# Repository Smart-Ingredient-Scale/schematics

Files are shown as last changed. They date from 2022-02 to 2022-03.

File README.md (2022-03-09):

# **ECE 477: Smart Kitchen Scale Schematics**

EAGLE PCB Design Tool

**Last Updated**: Mar 9, 2022

<h2 style="color: salmon" > <b> Repository Structure </b> </h2>

```
├── datasheets      # Directory for datasheets
├── docs            # file for library config
├── img             # Images folder for documentation
├── pcb             # Directory of schematics and board design files
└── README.md       

```

<h2 style="color: salmon" > <b> Schematic Design Responsibilities </b> </h2>

- [x] Design `Load Cell` subcircuit
- [x] Design `SPI Touchscreen` headers + &mu;C connections
- [x] Design `Battery Recharging` subcircuit
- [x] Design `Seven Segment Display` wire SPI pins + VDD/GND
- [x] Design `MCU Debugger` subcircuit
- [x] Integrate all submodules (MCU, battery, plugs, buttons, etc.)
- [x] Be a potato

<h2 style="color: salmon" > <b> Board Design Responsibilities </b> </h2>

- [x] Design PCB Revision 1.0.
- [ ] Verify PCB Revision 1.0 with course staff
- [ ] Order PCB via `JLCPCB` service
- [ ] Order a mask for component soldering via `JLCPCB` service

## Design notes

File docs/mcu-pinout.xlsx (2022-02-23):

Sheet: Pin Claiming
LQFP64 Pins | STM32F401RE Pin Number | Alternate Function | PCB Label |  | LQFP64 Pins | STM32F401RE Pin Number | Alternate Function | PCB Label
PA0 | 14 | ADC1_IN0 |  |  | PC0 | 8 | ADC1_IN10 | PC0
PA1 | 15 | ADC1_IN1 |  |  | PC1 | 9 | ADC_IN11 | PC1
PA2 | 16 | ADC1_IN2 |  |  | PC2 | 10 | ADC_IN12 | PC2
PA3 | 17 | ADC1_IN3 |  |  | PC3 | 11 | ADC_IN13 | PC3
PA4 | 20 | SPI1_NSS | SS_CS |  | PC4 | 24 | ADC1_IN14 | X-
PA5 | 21 | SPI1_SCK | SS_SCK |  | PC5 | 25 | ADC1_IN15 | Y-
PA6 | 22 | SPI1_MISO | SS_MISO |  | PC6 | 37 | --- | TFT_DC
PA7 | 23 | SPI1_MOSI | SS_MOSI |  | PC7 | 38 | --- | TFT_RST
PA8 | 41 | --- | SD_DC |  | PC8 | 39 | TIM3_CH3 | LITE
PA9 | 42 | --- | SD_DET |  | PC9 | 40 | --- | SD_CS
PA10 | 43 | TIM1_CH3 | PA10 |  | PC10 | 51 | SPI3_SCK | OLED_SCK
PA11 | 44 | TIM1_CH4 | PA11 |  | PC11 | 52 | --- | OLED_NSS
PA12 | 45 | TIM1_ETR | PA12 |  | PC12 | 53 | SPI3_MOSI | OLED_MOSI
PA13 | 46 | SWDIO | SWDIO |  | PC13 | 2
PA14 | 49 | SWCLK | SWCLK |  | PC14 | OSC32_IN | 32kHz Ext Osc |  | see next page
PA15 | 50 | JTDI |  |  | PC15 | OSC32_OUT | 32kHz Ext Osc |  | see next page
PB0 | 26 | ADC1_IN8 | Y+ |  | PD2 | 54 | ---
PB1 | 27 | ADC1_IN9 | X+
PB2 | 28 | --- |  |  | VBAT | 1 | --- | VDD
PB3 | 55 | SPIx_CLK | PB3 |  | PH0-OSC_IN | 5 | HSE Crystal | ???
PB4 | 56 | SPIx_MISO | PB4 |  | PH1-OSC_OUT | 6 | HSE Crystal | ???
PB5 | 57 | SPIx_MOSI | PB5 | del | nRST | 7 | --- | NRST
PB6 | 58 | I2C1_SCL | MEM_SCL |  | VSSA | 12 | VREF- Analog | GND
PB7 | 59 | I2C1_SDA | MEM_SDA |  | VDDA | 13 | VREF+ Analog | VDDA
PB8 | 61 | --- | HX_DATA |  | VSS | 18, 31, 47, 63 | GND | GND
PB9 | 62 | TIM4_CH4 | HX_CLK |  | VDD | 19, 32, 48, 64 | 3.3V | 3V3
PB10 | 29 |  |  |  | VCAP1 | 22 | PWR→VOS | 10uF || 100nF
PB11 | N/A |  |  |  | BOOT0 | 60 | ??? | GND
PB12 | 33 | --- | TFT_CS
PB13 | 34 | SPI2_CLK | TFT_SCK |  | KEY
PB14 | 35 | SPI2_MISO | TFT_MISO |  | Inflexible |  | See next page/sheet about hardware info
PB15 | 36 | SPI2_MOSI | TFT_MOSI |  | Preferable
 |  |  |  |  | Flexible | ← verify
 |  | Bold = using |  |  | Extra (Redundant) | ← low priority | Bold = using
 |  | normal = capable |  |  | Unused |  | normal = capable
 |  | --- = GPIO |  |  |  |  | --- = GPIO
 |  | (1) How do we specify our 3.3V LDO regulator, not internal? You don’t. You just provide 3.3V to VDD with the LDO. (2) How do we set our VDDA pin? Is it internally regulated? Same 3.3V source as VDD (or separate regulator). (3) How do we bias BOOT0? Tie to GND for SWD interface. (4) Are the PH0 and PH1 pins for the HSE crystal? Yes, they are. See the typical application circuit to the right. (5) Do we use VCAP1? If using internal regulator, 4.7uF low ESR, else 100nF. (6) What does VBAT do? What is the best biasing? Used only when VDD not present for RTC and backup. Tie to VDD.

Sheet: Power Supply Info
LQFP64 Pins | STM32F401RE Pin Number | Alternate Function | PCB Label | Design Notes
VBAT | 1 | --- | VDD
PH0-OSC_IN | 5 | HSE Crystal | HSE_IN | Use 16 Mhz oscillator
PH1-OSC_OUT | 6 | HSE Crystal | HSE_OUT | Use 16 Mhz oscillator
nRST | 7 | --- | NRST | Debounce using RC circuit
VSSA | 12 | VREF- Analog | GND | Attach to GND plane
VDDA | 13 | VREF+ Analog | VDDA | Same level as VDD
VSS | 18, 31, 47, 63 | GND | GND | Attach to GND plane
VDD | 19, 32, 48, 64 | 3.3V | 3V3 | Output of 3.3V external regulator
VCAP1 | 22 | --- | 10uF || 100nF | 1.2V (handle internally)
BOOT0 | 60 | --- | GND | Tie to GND if using SWD interface
KEY
Inflexible
Desirable
Flexible
Unused
 |  |  |  |  | (1) How do we specify our 3.3V LDO regulator, not internal? You don’t. You just provide 3.3V to VDD with the LDO. (2) How do we set our VDDA pin? Is it internally regulated? Same 3.3V source as VDD (or separate regulator). (3) How do we bias BOOT0? Tie to GND for SWD interface. (4) Are the PH0 and PH1 pins for the HSE crystal? Yes, they are. See the typical application circuit to the right. (5) Do we use VCAP1? If using internal regulator, 4.7uF low ESR, else 100nF. (6) What does VBAT do? What is the best biasing? Used only when VDD not present for RTC and backup. Tie to VDD.

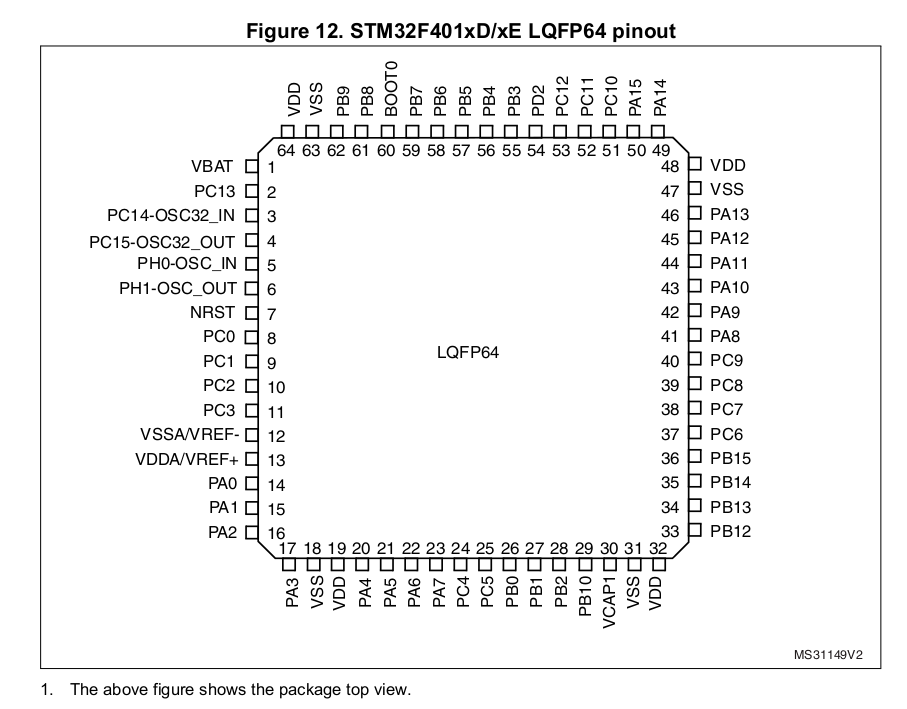
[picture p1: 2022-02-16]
img/stm32f401re-pinout.png

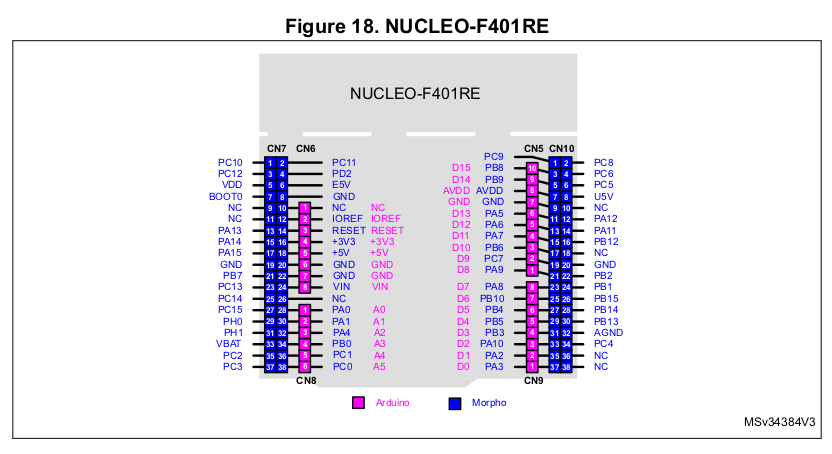
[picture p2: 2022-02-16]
img/nucleo-f401re-pinout.png

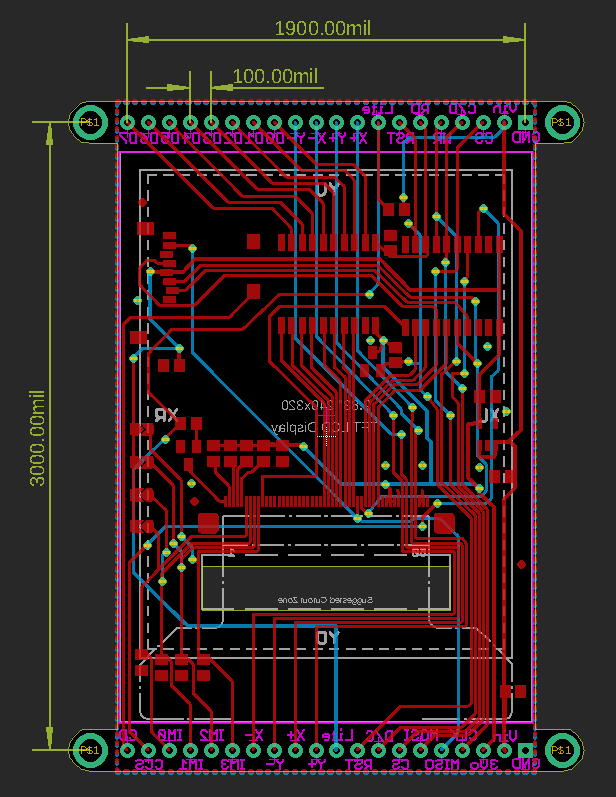
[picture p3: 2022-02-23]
img/lcd-tft-dimensions.png

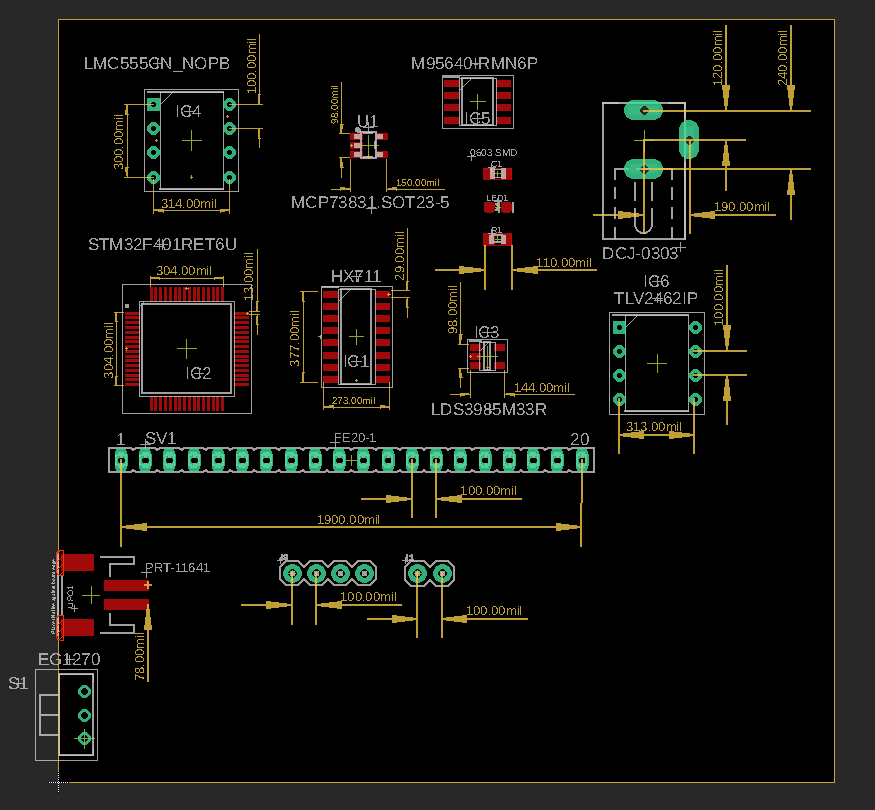
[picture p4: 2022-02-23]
img/pcb-footprints.png

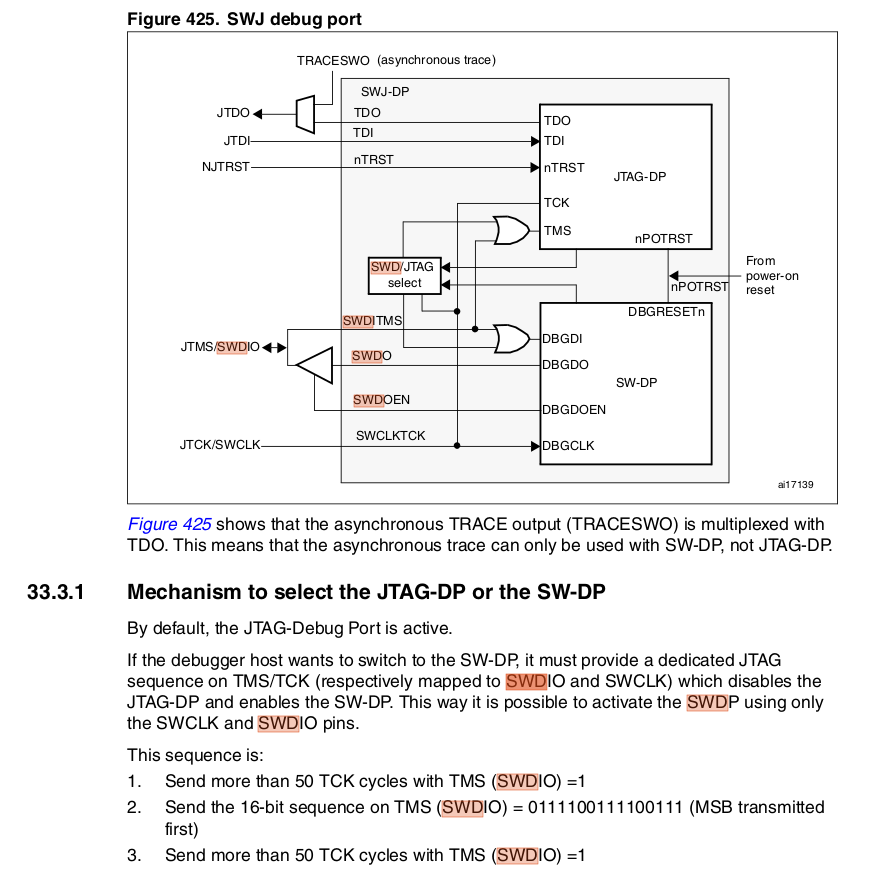
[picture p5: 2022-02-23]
img/swd-interface.png

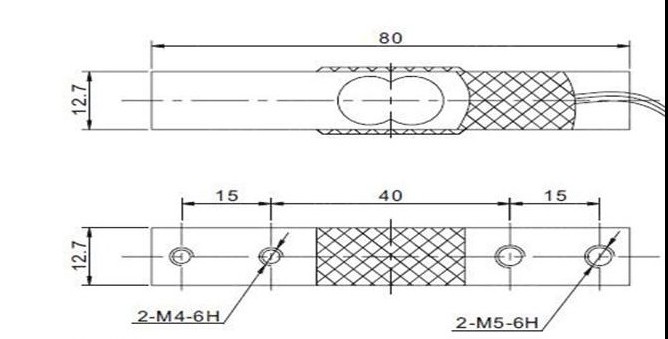
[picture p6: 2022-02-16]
img/load-cell-4540-dimensions.jpg

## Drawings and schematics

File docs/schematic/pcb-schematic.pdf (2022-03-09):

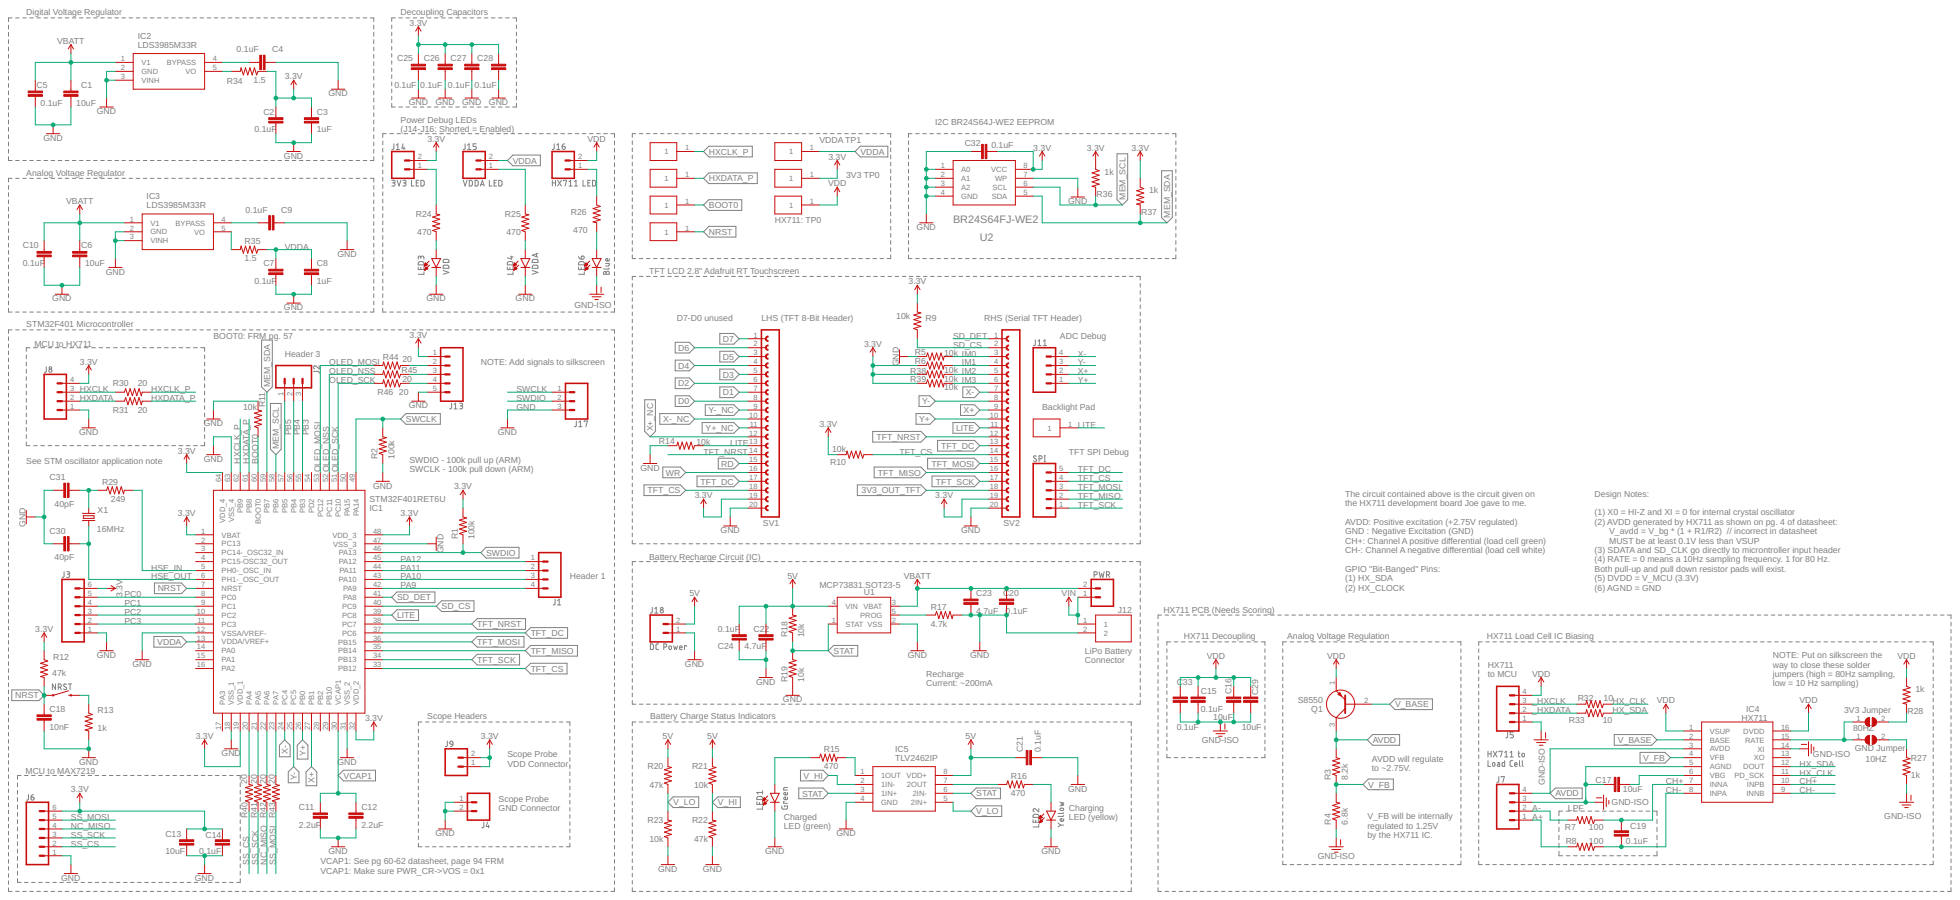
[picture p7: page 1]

Decoupling Capacitors
3.3V GND GND GND GND

TFT LCD 2.8" Adafruit RT Touchscreen

ADC Debug Backlight Pad TFT SPI Debug

NOTE: Add signals to silkscreen

See STM oscillator application note

SWDIO - 100k pull up (ARM) SWCLK - 100k pull down (ARM)

The circuit contained above is the circuit given on
the HX711 development board Joe gave to me. AVDD: Positive excitation (+2.75V regulated) GND : Negative Excitation (GND) CH+: Channel A positive differential (load cell green) CH-: Channel A negative differential (load cell white) GPIO "Bit-Banged" Pins: (1) HX_SDA

Design Notes: (1) X0 = HI-Z and XI = 0 for internal crystal oscillator

(2) AVDD generated by HX711 as shown on pg. 4 of datasheet: V_avdd = V_bg * (1 + R1/R2) // incorrect in datasheet MUST be at least 0.1V less than VSUP

(3) SDATA and SD_CLK go directly to microntroller input header
(4) RATE = 0 means a 10Hz sampling frequency. 1 for 80 Hz. Both pull-up and pull down resistor pads will exist. (5) DVDD = V_MCU (3.3V)

Battery Recharge Circuit (IC)

Battery Charge Status Indicators

Scope Probe GND Connector

LPF VCAP1: See pg 60-62 datasheet, page 94 FRM
2.2uF GND

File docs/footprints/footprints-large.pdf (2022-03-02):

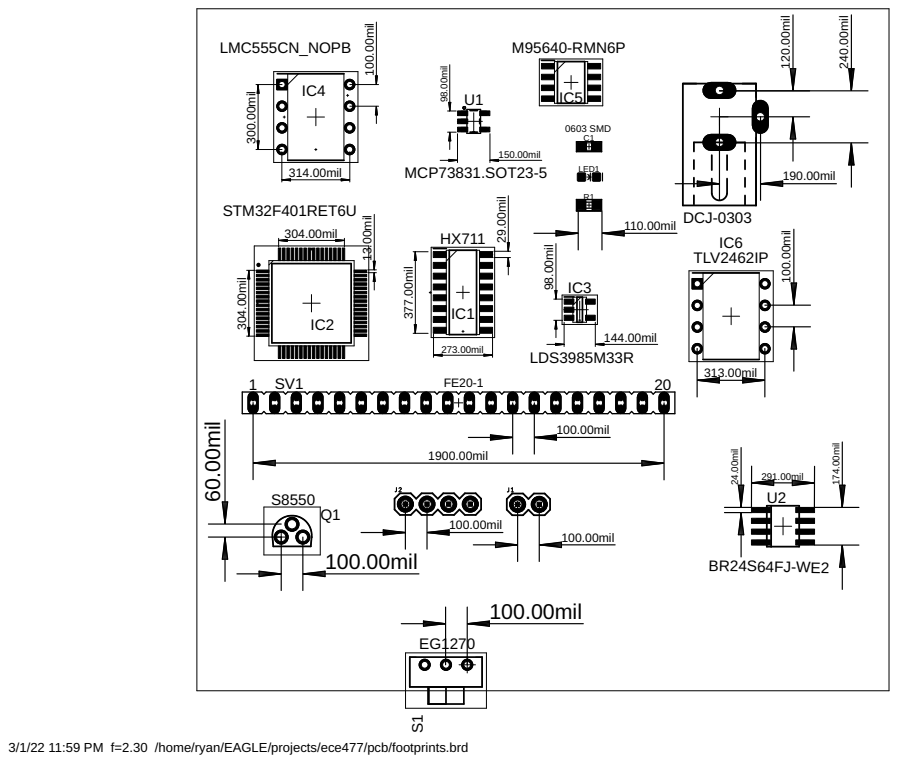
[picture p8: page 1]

3/1/22 11:59 PM f=2.30 /home/ryan/EAGLE/projects/ece477/pcb/footprints.brd

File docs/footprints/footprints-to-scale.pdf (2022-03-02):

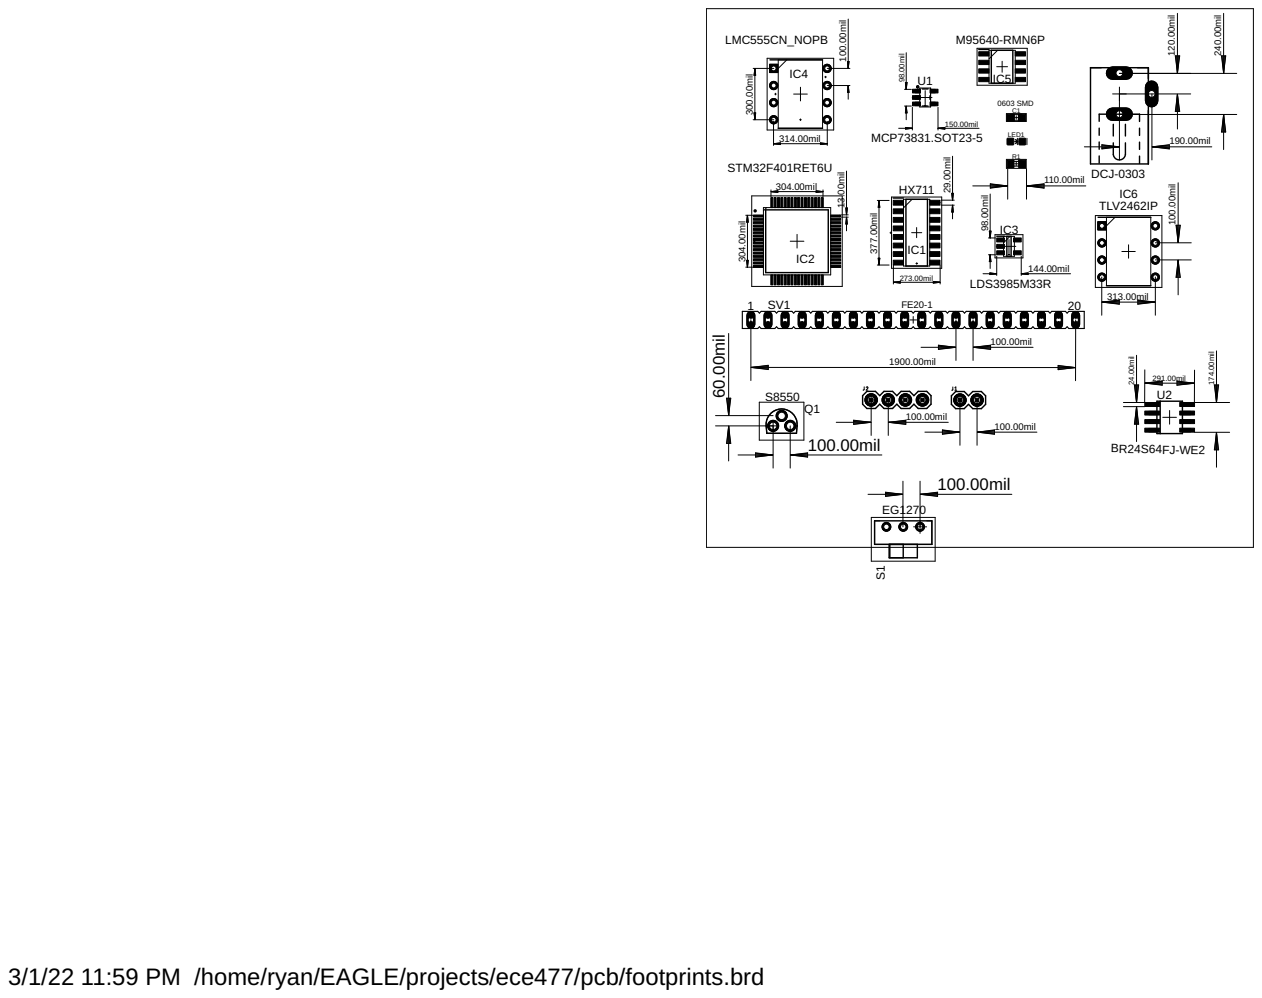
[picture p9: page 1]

3/1/22 11:59 PM /home/ryan/EAGLE/projects/ece477/pcb/footprints.brd

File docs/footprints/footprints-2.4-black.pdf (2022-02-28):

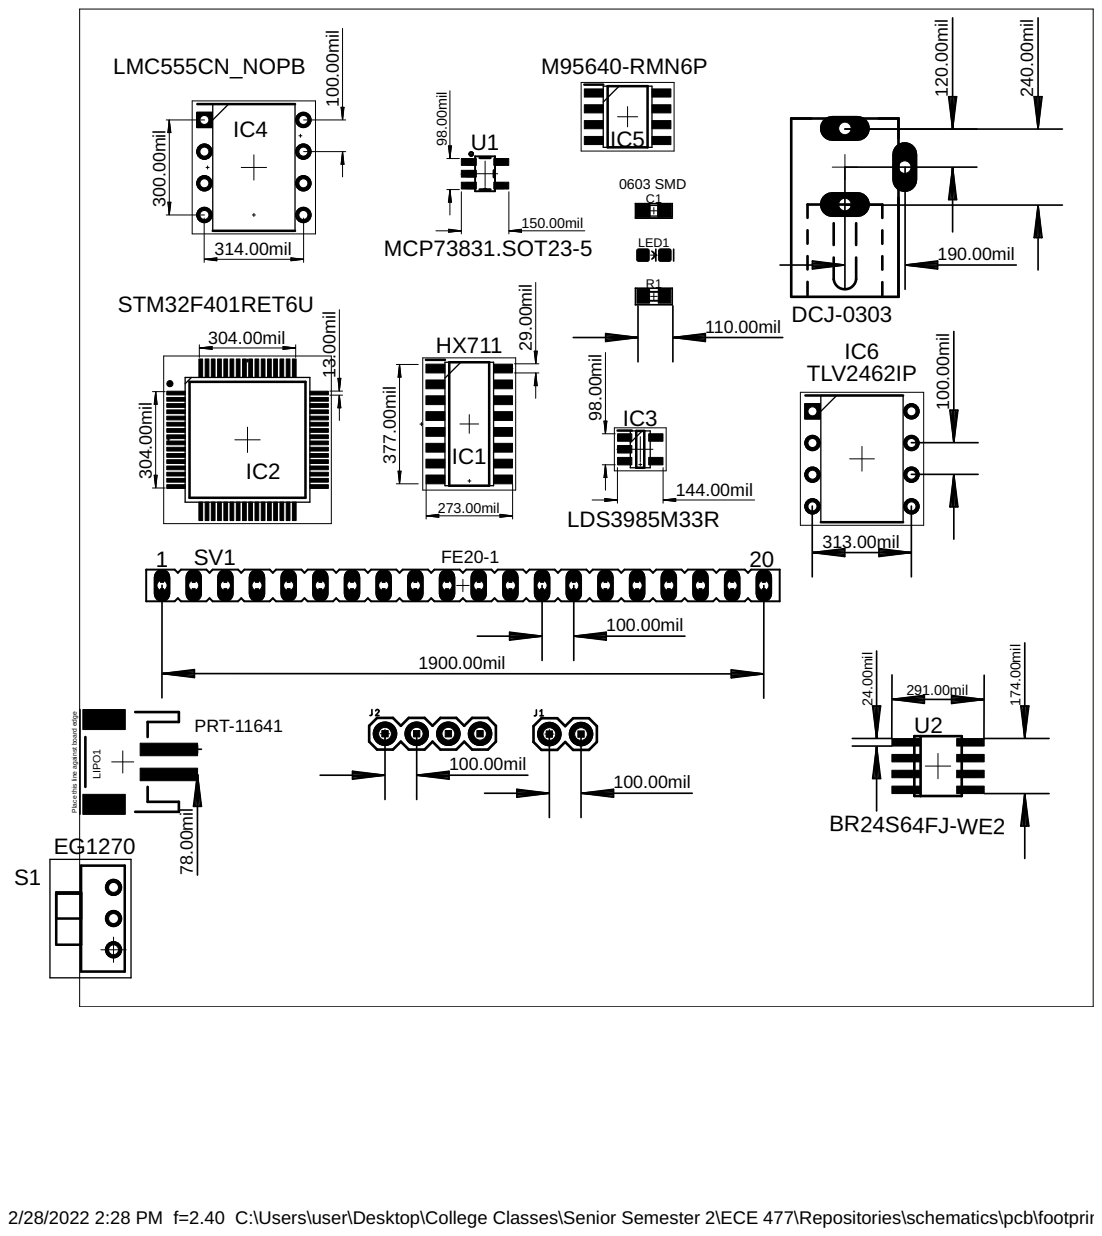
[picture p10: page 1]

Place this line against board edge

2/28/2022 2:28 PM f=2.40 C:\Users\user\Desktop\College Classes\Senior Semester 2\ECE 477\Repositories\schematics\pcb\footprints.brd

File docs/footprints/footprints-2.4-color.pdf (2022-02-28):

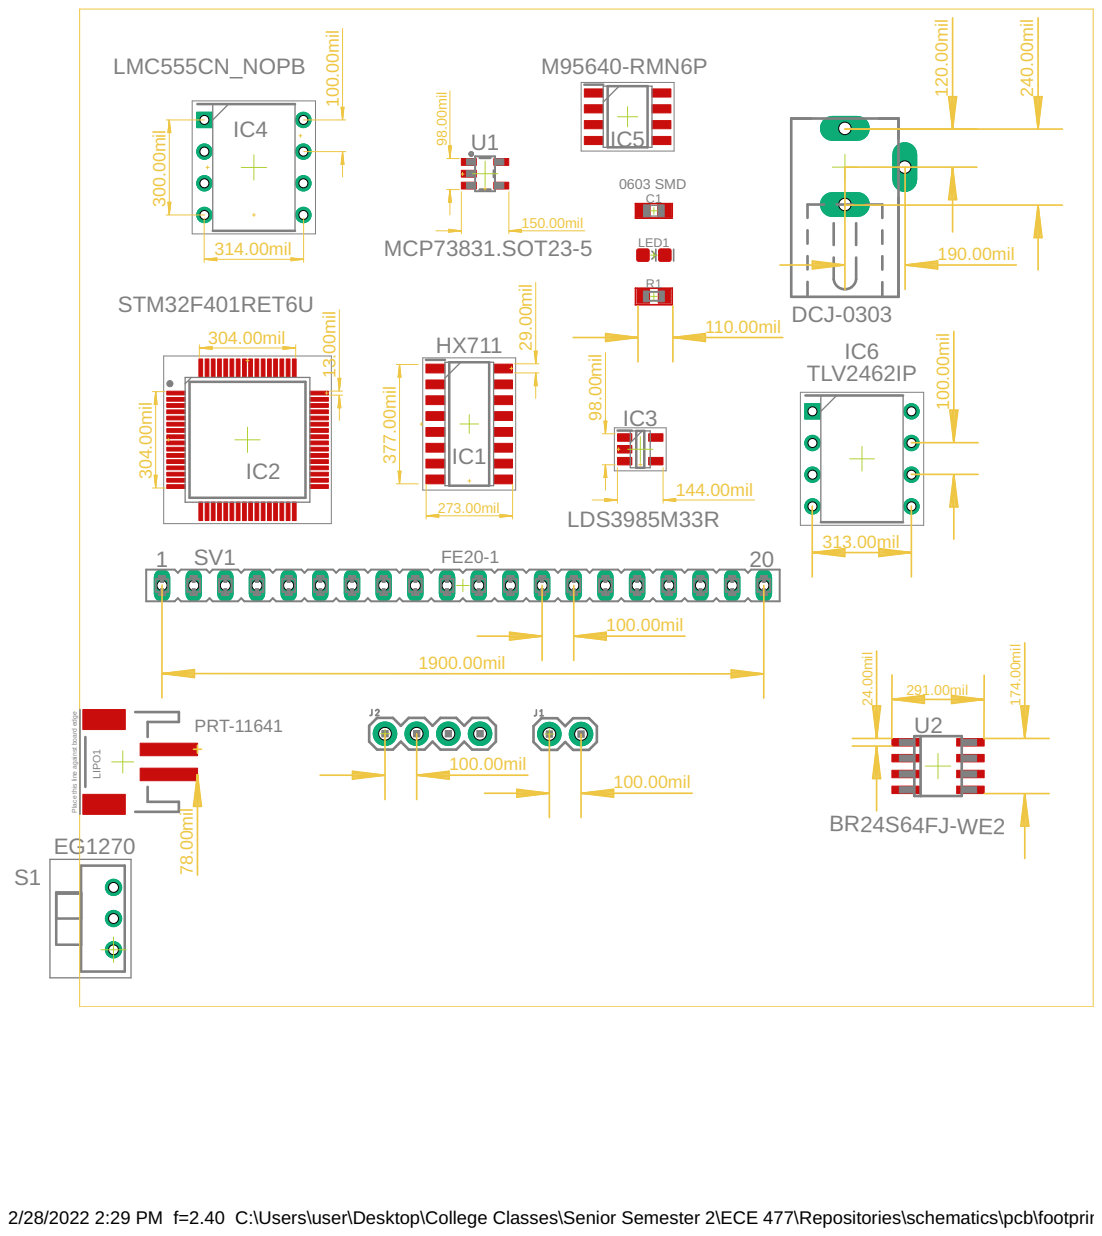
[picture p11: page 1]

Place this line against board edge

2/28/2022 2:29 PM f=2.40 C:\Users\user\Desktop\College Classes\Senior Semester 2\ECE 477\Repositories\schematics\pcb\footprints.brd

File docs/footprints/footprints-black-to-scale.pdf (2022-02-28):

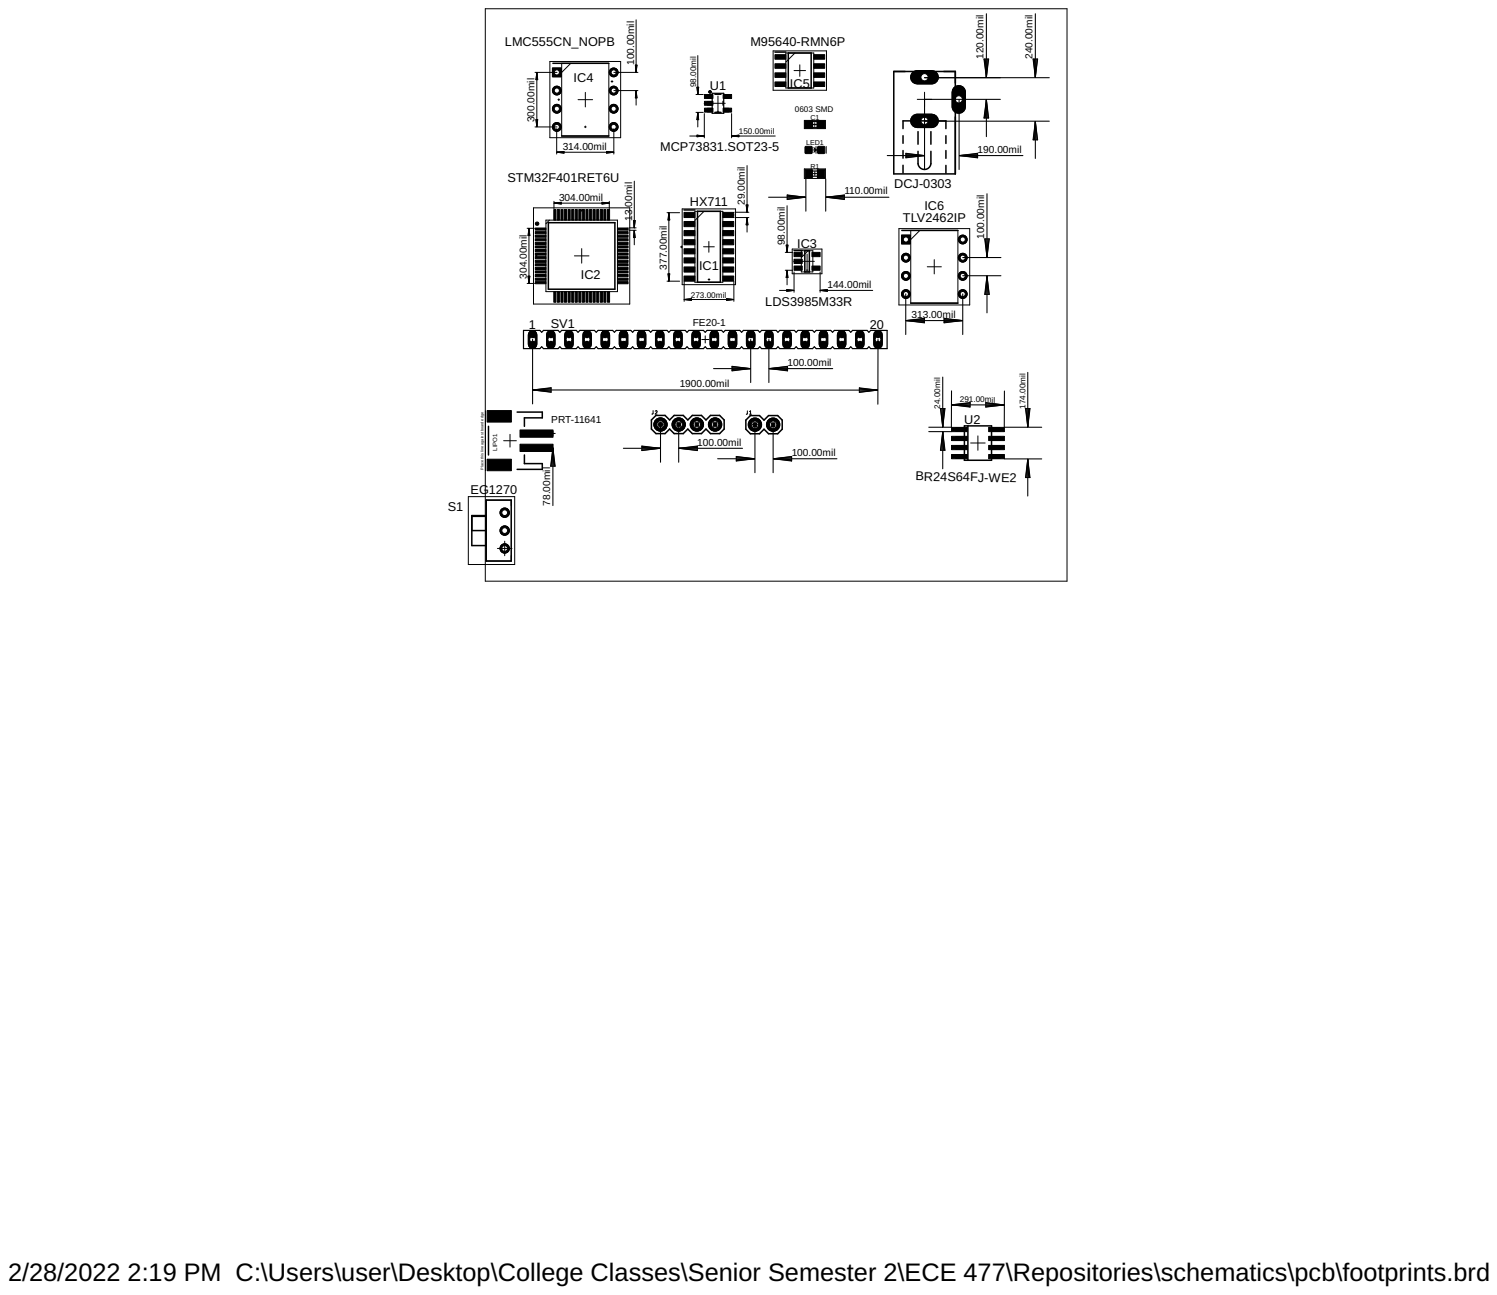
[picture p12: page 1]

Place this line against board edge

2/28/2022 2:19 PM C:\Users\user\Desktop\College Classes\Senior Semester 2\ECE 477\Repositories\schematics\pcb\footprints.brd

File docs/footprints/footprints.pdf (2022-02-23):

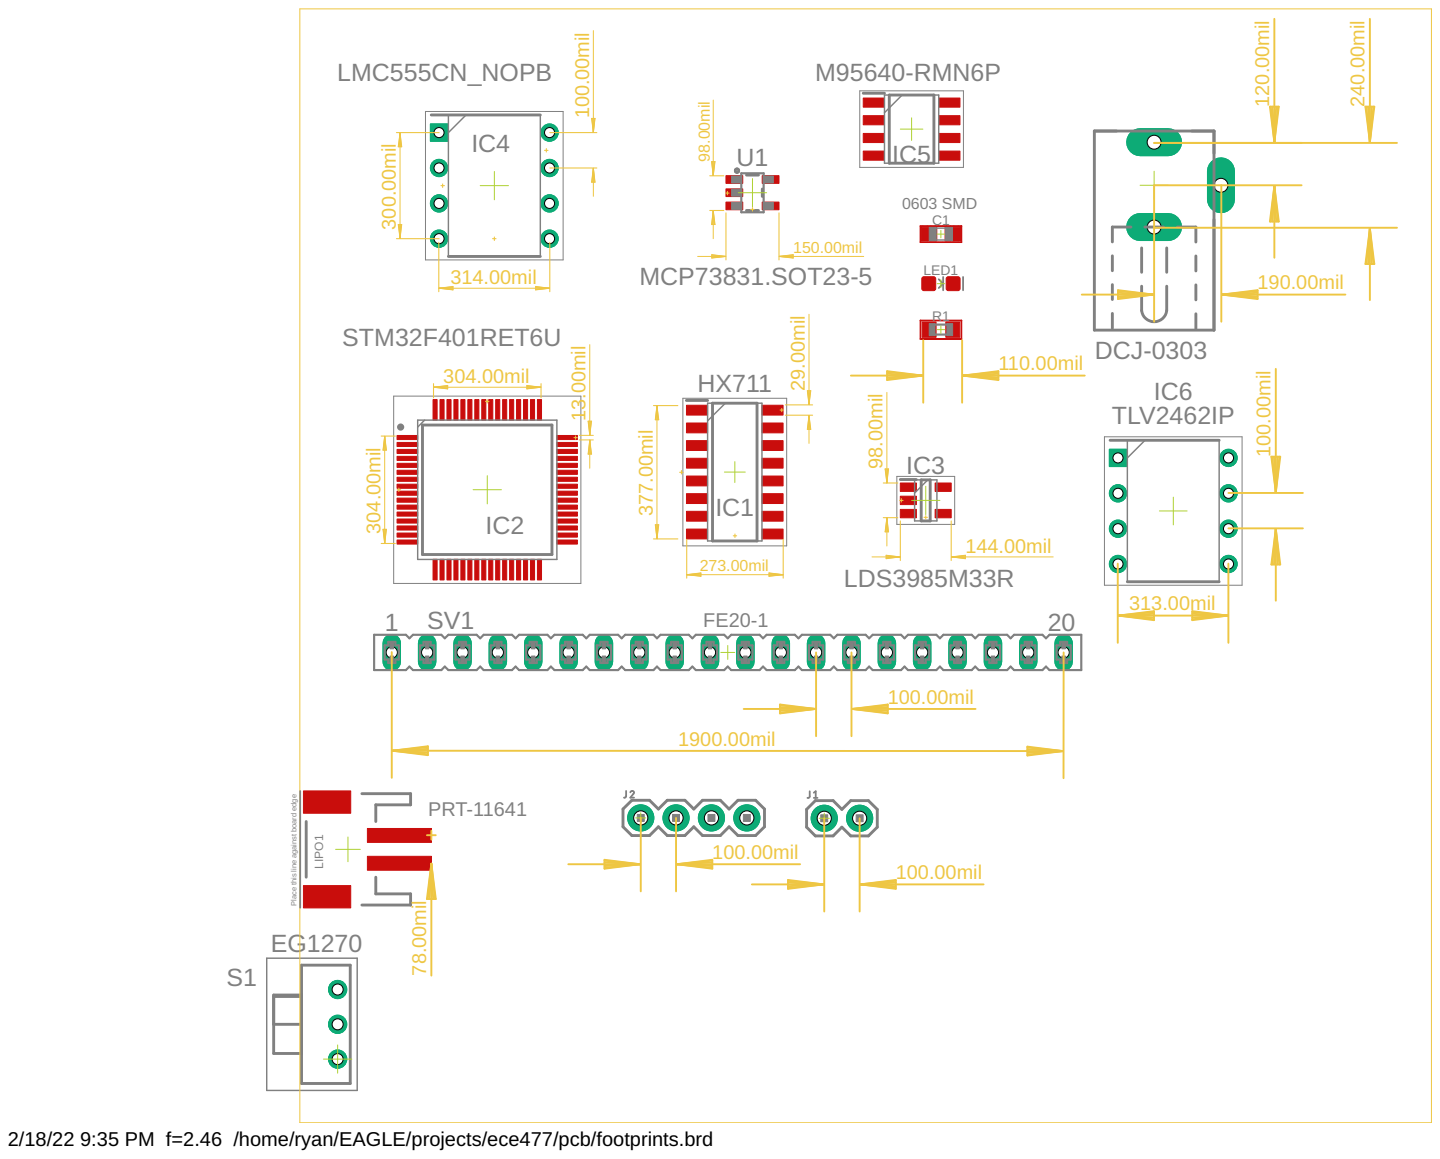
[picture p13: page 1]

100.00mil Place this line against board edge

2/18/22 9:35 PM f=2.46 /home/ryan/EAGLE/projects/ece477/pcb/footprints.brd

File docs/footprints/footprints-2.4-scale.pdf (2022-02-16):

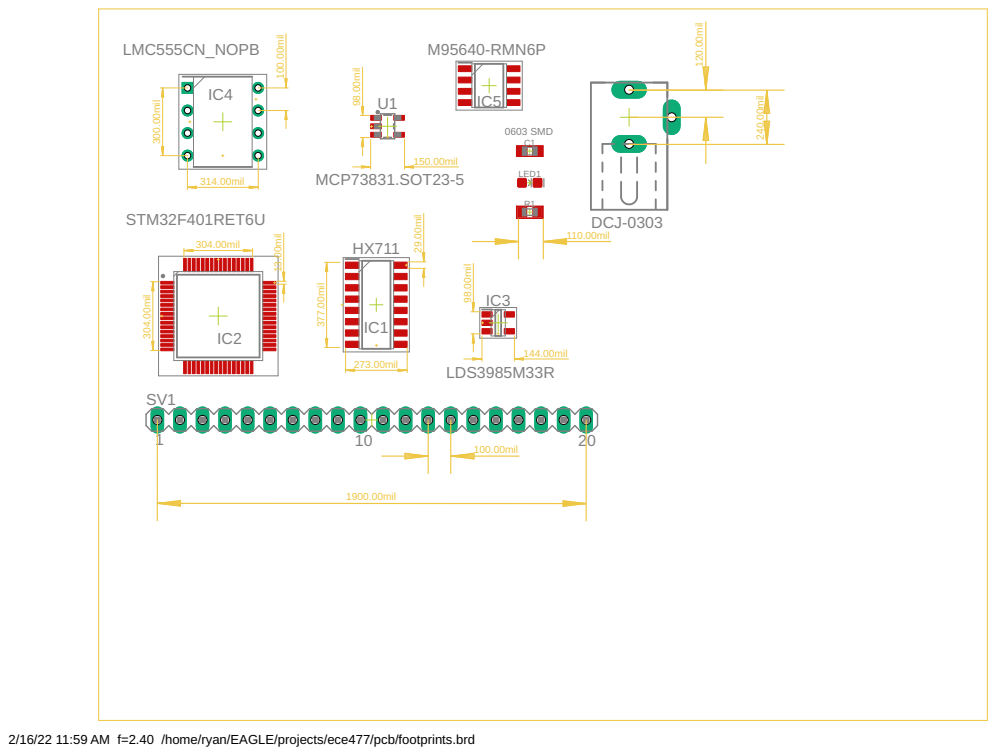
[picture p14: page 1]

2/16/22 11:59 AM f=2.40 /home/ryan/EAGLE/projects/ece477/pcb/footprints.brd

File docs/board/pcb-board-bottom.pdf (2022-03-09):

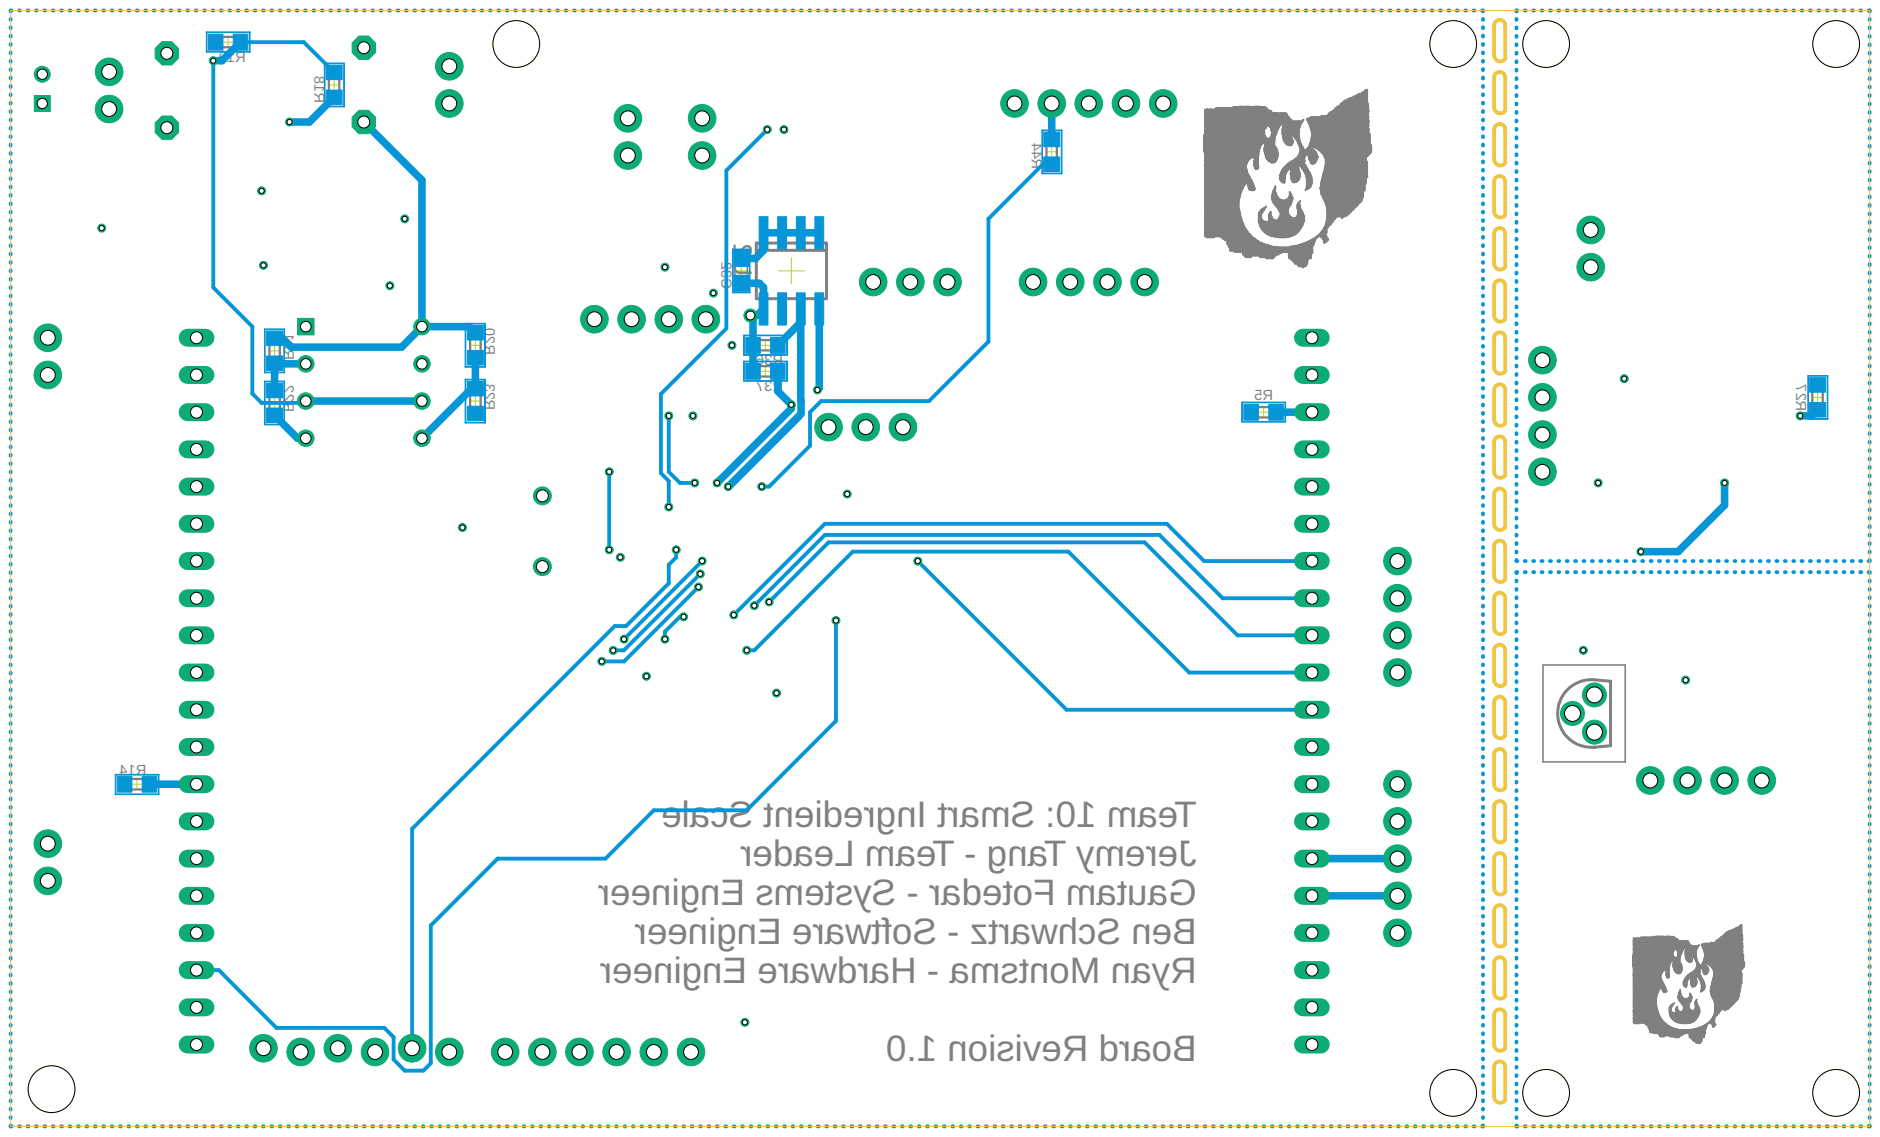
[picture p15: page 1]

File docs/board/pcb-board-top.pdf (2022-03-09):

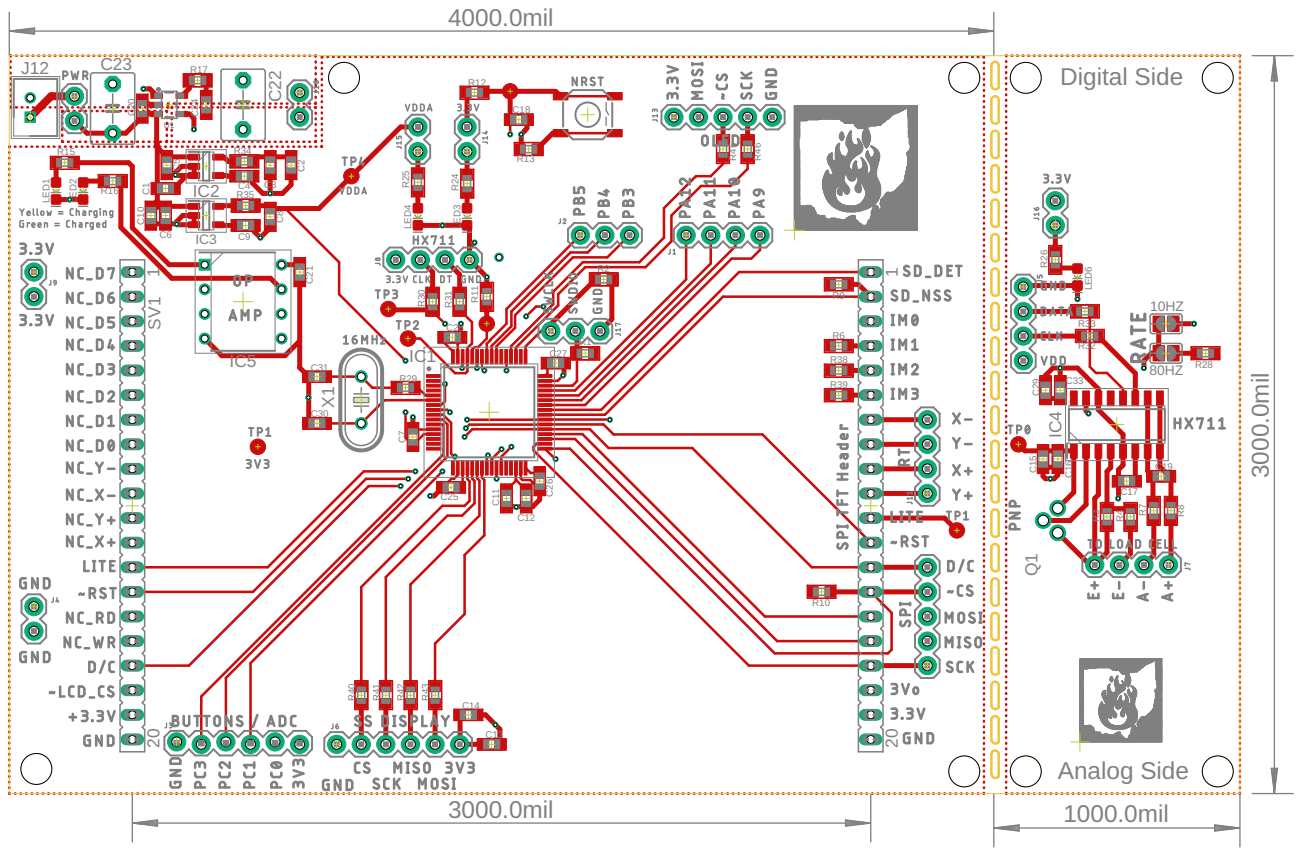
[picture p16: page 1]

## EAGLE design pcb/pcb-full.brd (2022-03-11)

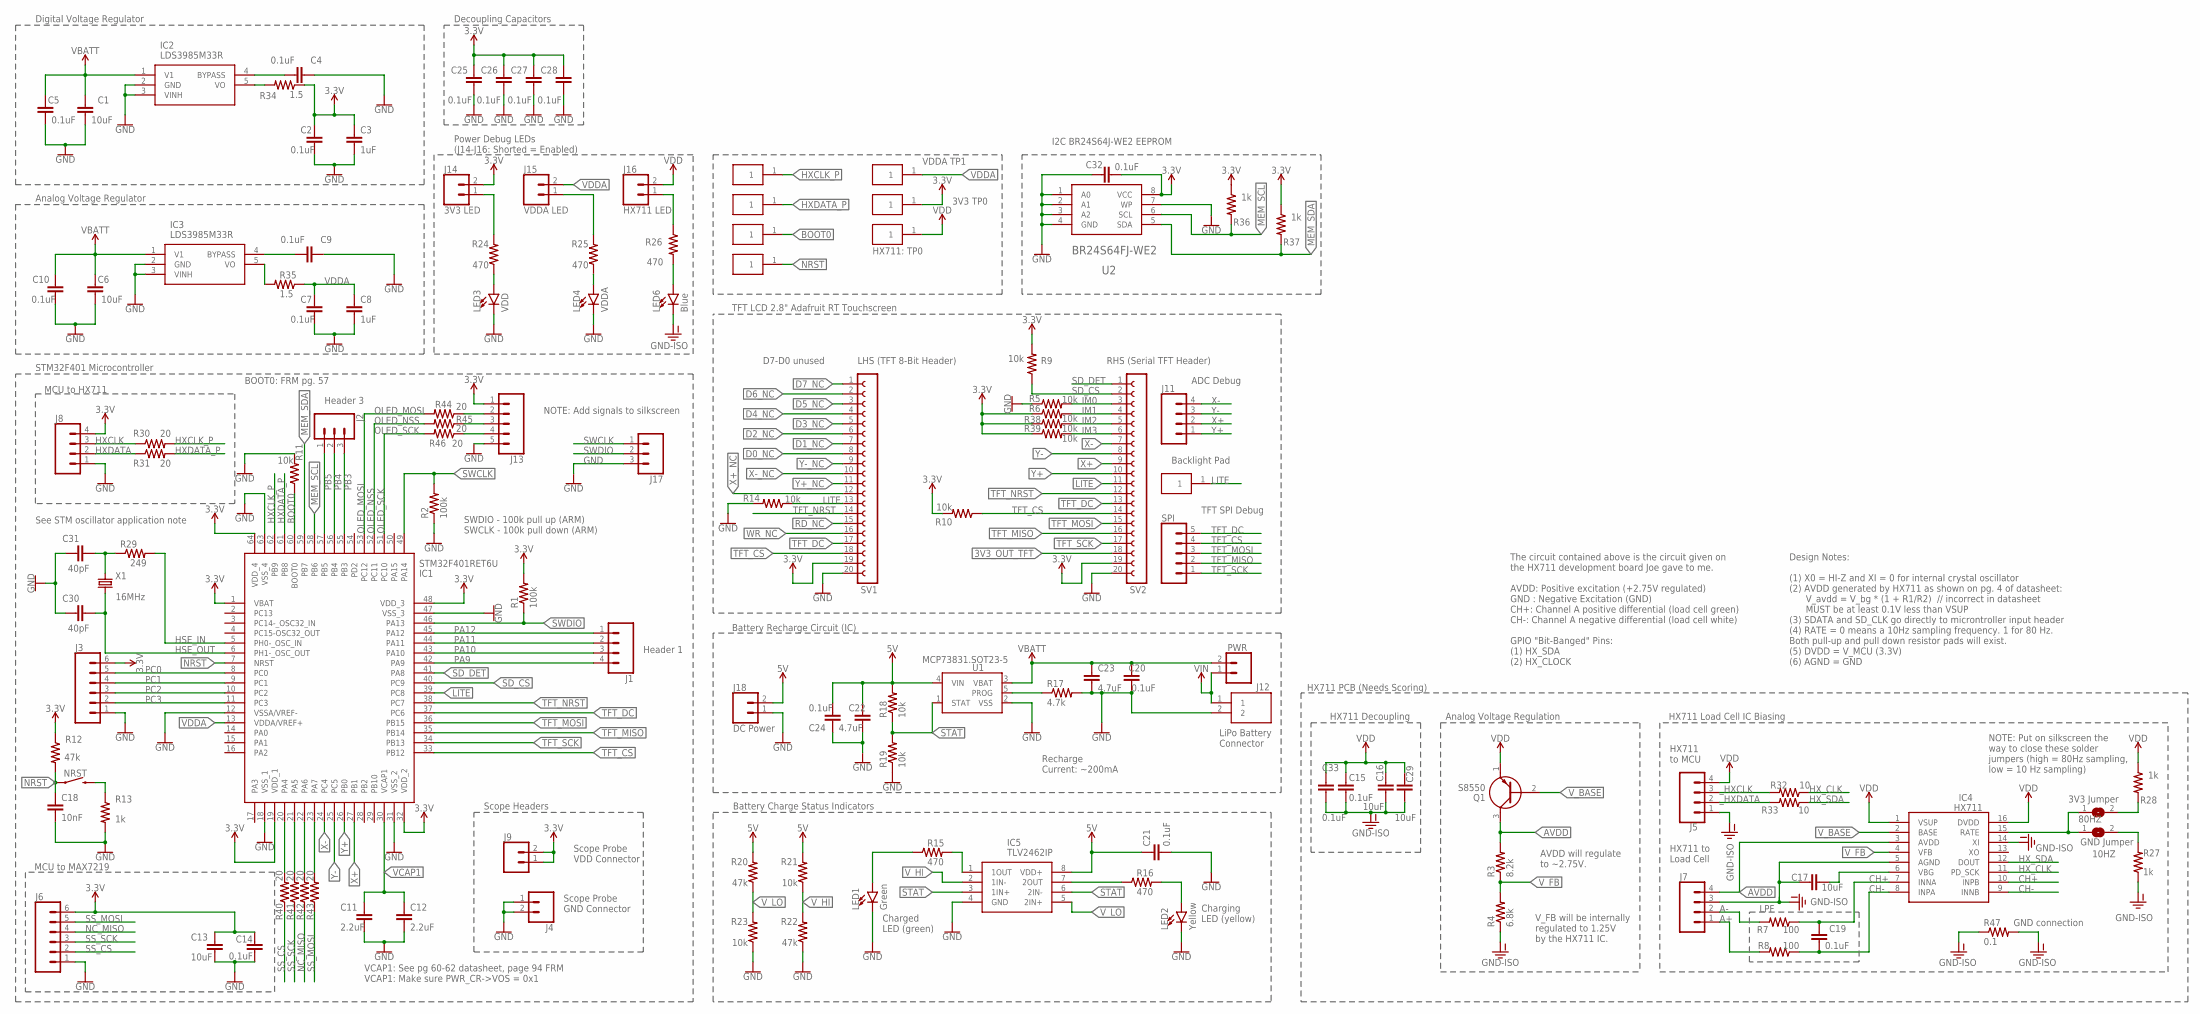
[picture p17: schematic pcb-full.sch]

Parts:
10HZ: GND Jumper; SJ
80HZ: 3V3 Jumper; SJ
C1, C6, C13, C16, C17, C29: 10uF; C0603
C2, C4, C5, C7, C9, C10, C14, C15, C19, C20, C21, C24, C25, C26, C27, C28, C32, C33: 0.1uF; C0603
C3, C8: 1uF; C0603
C11, C12: 2.2uF; C0603
C18: 10nF; C0603
C22, C23: 4.7uF; C5B4.5
C30, C31: 40pF; C0603
IC1: STM32F401RET6U; QFP50P1200X1200X160-64N
IC2, IC3: LDS3985M33R; SOT95P280X145-5N
IC4: HX711; SOIC127P600X160-16N
IC5: TLV2462IP; DIP794W53P254L959H508Q8N
J1, J5, J7, J8, J11: CONN_04; 1X04
J2, J17: CONN_03; 1X03
J3, J6: CONN_06SILK_FEMALE_PTH; 1X06
J4, J9: CONN_02; 1X02
J12: B2B-PH-K-S_LF__SN_; SHDR2W50P0X200_1X2_590X450X600
J13: CONN_05; 1X05
J14: 3V3 LED; 1X02
J15: VDDA LED; 1X02
J16: HX711 LED; 1X02
J18: DC Power; 1X02
LED1: Green; LED-0603
LED2: Yellow; LED-0603
LED3: VDD; LED-0603
LED4: VDDA; LED-0603
LED6: Blue; LED-0603
NRST: MOMENTARY-SWITCH-SPST-SMD-5.2-REDUNDANT; TACTILE_SWITCH_SMD_5.2MM
PWR: CONN_02; 1X02
Q1: S8550; MJE13001TP
R1, R2: 100k; R0603
R3: 8.2k; R0603
R4: 6.8k; R0603
R5, R6, R9, R10, R11, R14, R18, R19, R21, R23, R38, R39: 10k; R0603
R7, R8: 100; R0603
R12, R20, R22: 47k; R0603
R13, R27, R28, R36, R37: 1k; R0603
R15, R16, R24, R25, R26: 470; R0603
R17: 4.7k; R0603
R29: 249; R0603
R30, R31, R40, R41, R42, R43, R44, R45, R46: 20; R0603
R32, R33: 10; R0603
R34, R35: 1.5; R0603
R47: 0.1; R0603
SPI: CONN_05; 1X05
SV1: LHS (TFT 8-Bit Header); FE20
SV2: RHS (Serial TFT Header); FE20
U1: MCP73831.SOT23-5; SOT23-5
U2: BR24S64FJ-WE2; SOIC8
U$1, U$6: TP1; PAD
U$2: TP3; PAD
U$3: TP4; PAD
U$4: TP5; PAD
U$5: TP6; PAD
U$7: TP0; PAD
U$8: TP2; PAD
X1: 16MHz; HC49/S

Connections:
3.3V: C2.1, C3.1, C13.1, C14.1, C25.1, C26.1, C27.1, C28.1, C32.2, IC1.1 (VBAT), IC1.19 (VDD_1), IC1.32 (VDD_2), IC1.48 (VDD_3), IC1.64 (VDD_4), J3.6, J6.6, J8.4, J9.1, J9.2, J13.1, J14.2, R1.2, R6.1, R9.2, R10.2, R12.1, R34.1, R36.1, R37.1, R38.1, R39.1, SV1.19, SV2.19, U2.8 (VCC), U$7.1
3V3_LED: J14.1, R24.2
3V3_OUT_TFT: SV2.18
5V: C21.1, C22.1, C24.2, IC5.8 (VDD+), J18.2, R18.2, R20.2, R21.2, U1.4 (VIN)
A+: J7.1, R8.2
A-: J7.2, R7.2
ANA_LED: J15.1, R25.2
AVDD: IC4.3 (AVDD), J7.4, Q1.3 (C), R3.2
BOOT0: IC1.60 (BOOT0), R11.1, U$4.1
CH+: C19.1, IC4.7 (INNA), IC4.10 (INPB), R7.1
CH-: C19.2, IC4.8 (INPA), IC4.9 (INNB), R8.1
D0_NC: SV1.8
D1_NC: SV1.7
D2_NC: SV1.6
D3_NC: SV1.5
D4_NC: SV1.4
D5_NC: SV1.3
D6_NC: SV1.2
D7_NC: SV1.1
GND: C1.2, C2.2, C3.2, C4.1, C5.2, C6.2, C7.2, C8.2, C9.1, C10.2, C11.2, C12.2, C13.2, C14.2, C18.2, C20.2, C21.2, C22.2, C23.2, C24.1, C25.2, C26.2, C27.2, C28.2, C30.1, C31.1, C32.1, IC1.12 (VSSA/VREF-), IC1.18 (VSS_1), IC1.31 (VSS_2), IC1.47 (VSS_3), IC1.63 (VSS_4), IC2.2 (GND), IC2.3 (VINH), IC3.2 (GND), IC3.3 (VINH), IC5.4 (GND), J3.1, J4.1, J4.2, J6.1, J8.1, J12.2, J13.5, J17.3, J18.1, LED1.C, LED2.C, LED3.C, LED4.C, R2.1, R5.1, R11.2, R13.2, R14.2, R17.2, R19.1, R22.1, R23.1, SV1.20, SV2.20, U1.2 (VSS), U2.1 (A0), U2.2 (A1), U2.3 (A2), U2.4 (GND), U2.7 (WP)
GND-ISO: C15.2, C16.2, C17.1, C29.2, C33.2, IC4.5 (AGND), IC4.14 (XI), J5.1, J7.3, LED6.C, R4.1, R27.1, R47.1, R47.2
HSE_IN: IC1.5 (PH0-_OSC_IN), R29.2
HSE_OUT: C30.2, IC1.6 (PH1-_OSC_OUT), X1.1
HXCLK: J8.3, R30.1
HXCLK_P: IC1.62 (PB9), R30.2, U$2.1
HXDATA: J8.2, R31.1
HXDATA_P: IC1.61 (PB8), R31.2, U$3.1
HX_CLK: IC4.11 (PD_SCK), R32.1
HX_LED: J16.1, R26.1
HX_SDA: IC4.12 (DOUT), R33.1
IM0: R5.2, SV2.3
IM1: R6.2, SV2.4
IM2: R38.2, SV2.5
IM3: R39.2, SV2.6
LITE: IC1.39 (PC8), R14.1, SV1.13, SV2.11, U$1.1
MEM_SCL: IC1.58 (PB6), R36.2, U2.6 (SCL)
MEM_SDA: IC1.59 (PB7), R37.2, U2.5 (SDA)
unnamed: C9.2, IC3.4 (BYPASS)
unnamed: LED1.A, R15.1
unnamed: C4.2, IC2.4 (BYPASS)
unnamed: IC5.7 (2OUT), R16.1
unnamed: LED2.A, R16.2
unnamed: IC5.1 (1OUT), R15.2
unnamed: R17.1, U1.5 (PROG)
unnamed: J13.2, R44.1
unnamed: LED4.A, R25.1
unnamed: 10HZ.2, R27.2
unnamed: C17.2, IC4.6 (VBG)
unnamed: 10HZ.1, 80HZ.1, IC4.15 (RATE)
unnamed: LED3.A, R24.1
unnamed: LED6.A, R26.2
unnamed: IC3.5 (VO), R35.2
unnamed: 80HZ.2, R28.2
unnamed: NRST.3 (2), NRST.4 (2), R13.1
unnamed: C31.2, R29.1, X1.2
unnamed: IC2.5 (VO), R34.2
unnamed: J13.3, R45.1
unnamed: J13.4, R46.1
NC_MISO: J6.4, R42.1
NRST: C18.1, IC1.7 (NRST), NRST.1, NRST.2 (1), R12.2, U$5.1
OLED_MOSI: IC1.53 (PC12), R44.2
OLED_NSS: IC1.52 (PC11), R45.2
OLED_SCK: IC1.51 (PC10), R46.2
PA9: IC1.42 (PA9), J1.4
PA10: IC1.43 (PA10), J1.3
PA11: IC1.44 (PA11), J1.2
PA12: IC1.45 (PA12), J1.1
PB3: IC1.55 (PB3), J2.3
PB4: IC1.56 (PB4), J2.2
PB5: IC1.57 (PB5), J2.1
PC0: IC1.8 (PC0), J3.5
PC1: IC1.9 (PC1), J3.4
PC2: IC1.10 (PC2), J3.3
PC3: IC1.11 (PC3), J3.2
RD_NC: SV1.15
SD_CS: IC1.40 (PC9), R9.1, SV2.2
SD_DET: IC1.41 (PA8), SV2.1
SS_CS: J6.2, R40.1
SS_MOSI: J6.5, R43.1
SS_SCK: J6.3, R41.1
STAT: IC5.3 (1IN+), IC5.6 (2IN-), R18.1, R19.2, U1.1 (STAT)
SWCLK: IC1.49 (PA14), J17.1, R2.2
SWDIO: IC1.46 (PA13), J17.2, R1.1
TFT_CS: IC1.33 (PB12), R10.1, SPI.4, SV1.18, SV2.14
TFT_DC: IC1.37 (PC6), SPI.5, SV1.17, SV2.13
TFT_MISO: IC1.35 (PB14), SPI.2, SV2.16
TFT_MOSI: IC1.36 (PB15), SPI.3, SV2.15
TFT_NRST: IC1.38 (PC7), SV1.14, SV2.12
TFT_SCK: IC1.34 (PB13), SPI.1, SV2.17
VCAP1: C11.1, C12.1, IC1.30 (VCAP1)
VDD: C15.1, C16.1, C29.1, C33.1, IC4.1 (VSUP), IC4.16 (DVDD), J5.4, J16.2, Q1.1 (E), R28.1, U$8.1
VDDA: C7.1, C8.1, IC1.13 (VDDA/VREF+), J15.2, R35.1, U$6.1
VIN: J12.1, PWR.1
V_BASE: IC4.2 (BASE), Q1.2 (B)
V_BATT: C1.1, C5.1, C6.1, C10.1, C20.1, C23.1, IC2.1 (V1), IC3.1 (V1), PWR.2, U1.3 (VBAT)
V_FB: IC4.4 (VFB), R3.1, R4.2
V_HI: IC5.2 (1IN-), R21.1, R22.2
V_LO: IC5.5 (2IN+), R20.1, R23.2
WR_NC: SV1.16
X+: IC1.27 (PB1), J11.2, SV2.9
X+_NC: SV1.12
X-: IC1.24 (PC4), J11.4, SV2.7
X-_NC: SV1.10
Y+: IC1.26 (PB0), J11.1, SV2.10
Y+_NC: SV1.11
Y-: IC1.25 (PC5), J11.3, SV2.8
Y-_NC: SV1.9
_HXCLK: J5.3, R32.2
_HXDATA: J5.2, R33.2
_NC_MISO: IC1.22 (PA6), R42.2
_SS_CS: IC1.20 (PA4), R40.2
_SS_MOSI: IC1.23 (PA7), R43.2
_SS_SCK: IC1.21 (PA5), R41.2

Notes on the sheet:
Analog Voltage Regulator
Digital Voltage Regulator
SWDIO - 100k pull up (ARM) SWCLK - 100k pull down (ARM)
Header 1
Header 3
HX711 to MCU
The circuit contained above is the circuit given on the HX711 development board Joe gave to me. AVDD: Positive excitation (+2.75V regulated) GND : Negative Excitation (GND) CH+: Channel A positive differential (load cell green) CH-: Channel A negative differential (load cell white) GPIO "Bit-Banged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
HX711 Decoupling
Design Notes: (1) X0 = HI-Z and XI = 0 for internal crystal oscillator (2) AVDD generated by HX711 as shown on pg. 4 of datasheet: V_avdd = V_bg * (1 + R1/R2) // incorrect in datasheet MUST be at least 0.1V less than VSUP (3) SDATA and SD_CLK go directly to microntroller input header (4) RATE = 0 m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
Analog Voltage Regulation
V_FB will be internally regulated to 1.25V by the HX711 IC.
HX711 Load Cell IC Biasing
NOTE: Put on silkscreen the way to close these solder jumpers (high = 80Hz sampling, low = 10 Hz sampling)
AVDD will regulate to ~2.75V.
HX711 to Load Cell
STM32F401 Microcontroller
Scope Probe GND Connector
MCU to HX711
HX711 PCB (Needs Scoring)
D7-D0 unused
TFT LCD 2.8" Adafruit RT Touchscreen
MCU to MAX7219
Scope Probe VDD Connector
ADC Debug
Backlight Pad
TFT SPI Debug
Scope Headers
NOTE: Add signals to silkscreen
LPF
VCAP1: See pg 60-62 datasheet, page 94 FRM VCAP1: Make sure PWR_CR->VOS = 0x1
Charging LED (yellow)
Charged LED (green)
Recharge Current: ~200mA
Battery Charge Status Indicators
Battery Recharge Circuit (IC)
LiPo Battery Connector
Power Debug LEDs (J14-J16: Shorted = Enabled)
Decoupling Capacitors
BOOT0: FRM pg. 57
See STM oscillator application note

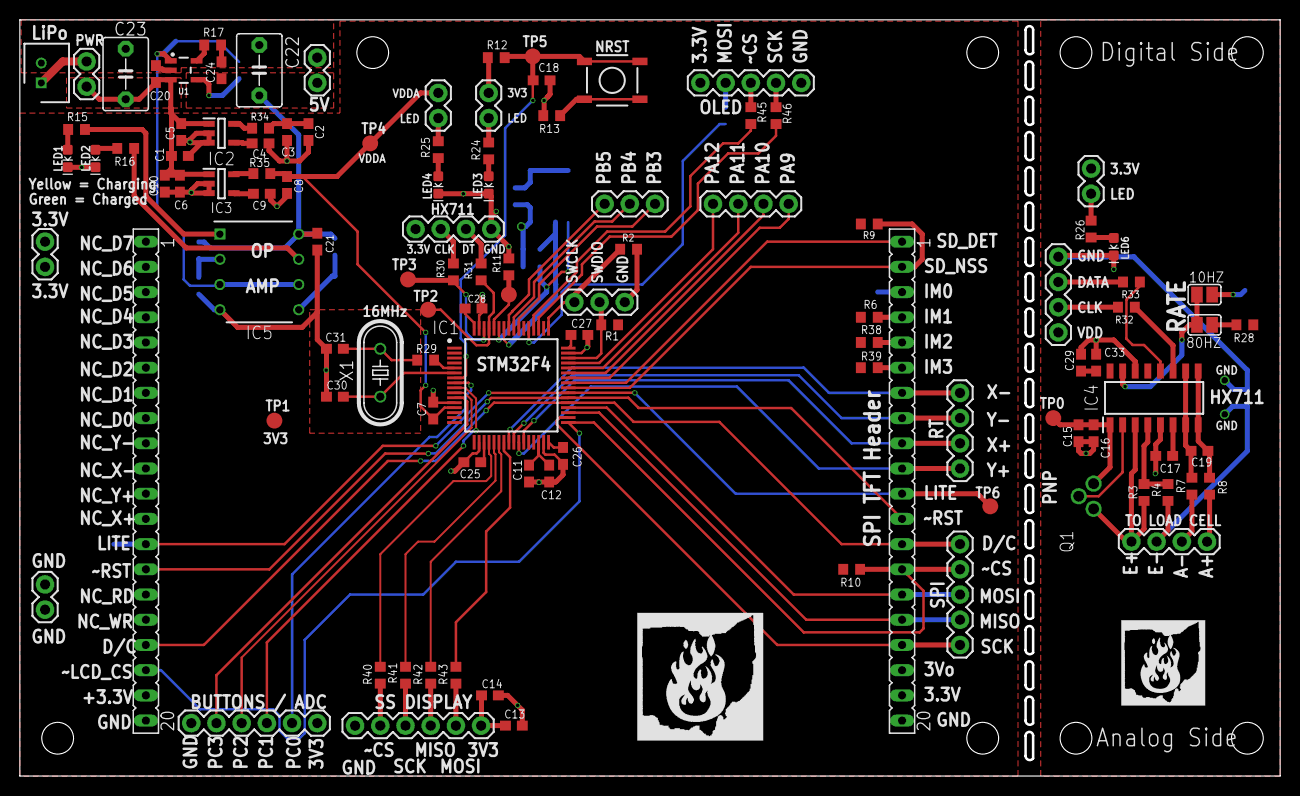
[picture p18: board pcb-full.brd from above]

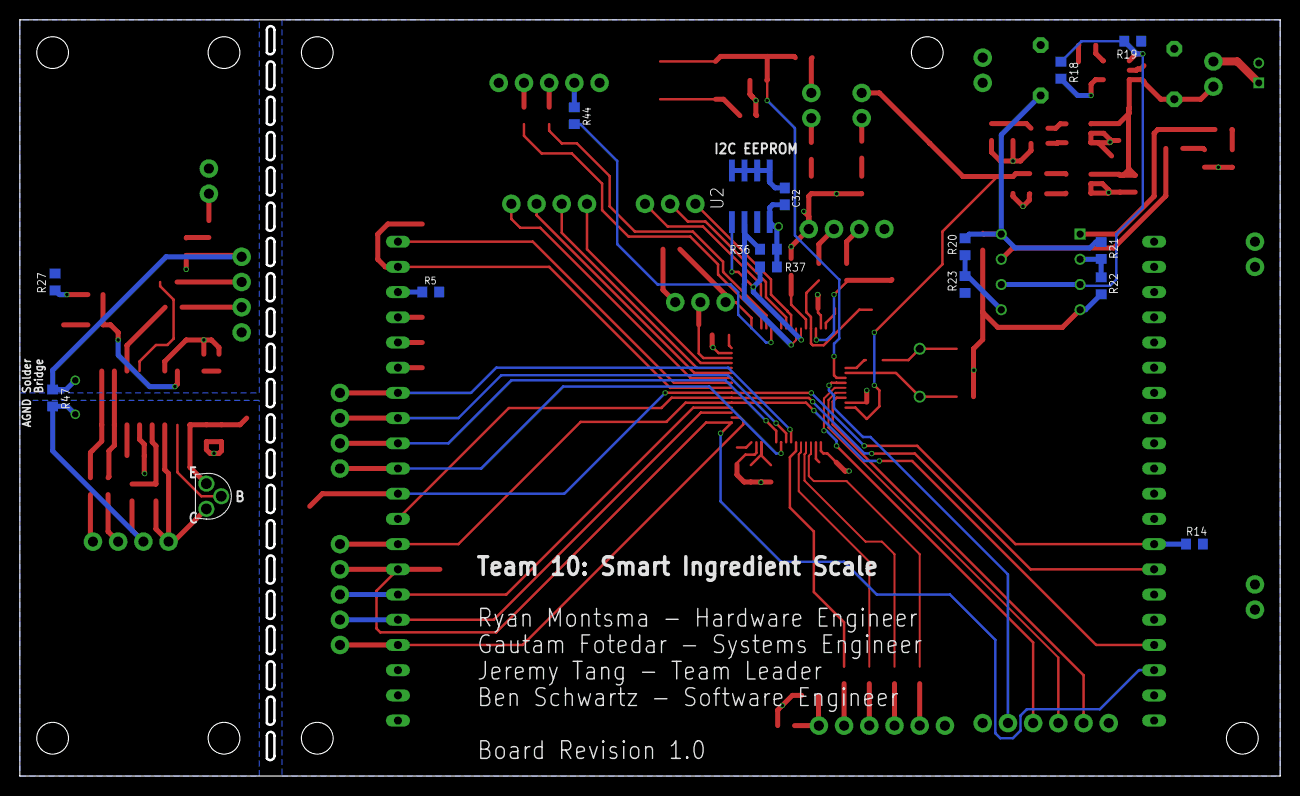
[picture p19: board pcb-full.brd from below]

Board: 2 copper layers, 127.0 x 76.2 mm, 128 parts (16 on the bottom side), 98 nets.

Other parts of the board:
U$9: BURNING-OHIO
U$10: BURNING-OHIO2

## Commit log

2022-01-19 Initialized the schematics repository w/ basic directory structure
2022-02-02 Updated the EAGLE schematic for the battery recharging circuit: verified
    [battery-charger.sch]
2022-02-02 Updated the battery recharging subcircuit documentation
2022-02-16 Updated the footprints barring the TLV2462 op amp and improper header
    [footprints.brd, footprints.sch, load-cell.sch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]
2022-02-16 Updated all relevent datasheets and images (pinouts). Need to summarize in README.md.
    [seven-segment.sch]
2022-02-23 Updated the PCB Schematic: 80% complete. Added PCB reference.
    [footprints.brd, footprints.sch, load-cell.sch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]
2022-02-23 Cleaned up the junk files
    [mcu-pinout.xlsx]
2022-02-25 Updated the schematic: Power supply and EEPROM: TBD
    [battery-charger.brd]
2022-02-26 Updated the PCB board and schematic. In process of generally laying down components. Will be working on the design for next 1.5 hours.
    [micro-board.brd, micro-board.sch]
2022-02-26 Updated the micro-board.brd file with power supply + basic polygons
    [micro-board.brd, micro-board.sch]
2022-02-26 Added first, somewhat flawed EEPROM footprint
2022-02-26 Updated power supply, decoupling, analog and digital GND
    [micro-board.brd]
2022-02-27 Updated I2C-EEPROM board footprint for pin renaming
2022-02-27 Final update to the I2C EEPROM lbr
2022-02-28 Final update to the I2C EEPROM lbr - Added necessary connection between schematic and pins
2022-02-28 Added I2C EEPROM Footprint to both schematic and board and dimensioned appropriately
    [footprints.brd, footprints.sch]
2022-02-28 Finished simplistic EEPROM routing on back of main board
    [micro-board.brd, micro-board.sch]
2022-02-28 Updated EEPROM Resistor Positions
    [micro-board.brd]
2022-02-28 Incremental commit of changes
    [micro-board.brd]
2022-02-28 Adding b&w footprint to scale
2022-02-28 Add Documentation for schematic and footprints
2022-03-01 Continued Routing (more in longer description)
    Added these subsystems routed:
    nrst for reset switch.
    HXDATA and HXCLK for the Micro's header.
    Boot0 pad
    Scope probe headers for GND and 3.3V
    [micro-board.brd]
2022-03-01 Updated TFT right-side header, debug headers, and routing
    [micro-board.brd, micro-board.sch]
2022-03-01 Incremental commit of changes made
    [micro-board.brd, micro-board.sch]
2022-03-01 Further PCB development
    [micro-board.brd]
2022-03-02 Updated the initial revision of the PCB + PDFs of layout
    [footprints.brd, footprints.sch, micro-board.brd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]
2022-03-09 Updated the PCB with more silkscreen and ESD protection resistors
    [micro-board.brd, micro-board.sch]
2022-03-09 Updated directory structure, cleaned up PCB, and updated README
    [battery-charger.brd, battery-charger.sch, load-cell.sch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]
2022-03-09 Updated the 8 mil trace clearance and DRC
    [pcb-full.brd, pcb-full.sch]
2022-03-10 Final version of the PCB? Updated headers + silkscreen + AGND
    [pcb-full.brd, pcb-full.sch]
2022-03-11 Finished updating the PCB + Gerber files zip file
    [pcb-full.brd]
2022-03-11 Updated the Gerber files (unzipped the archive)
    [drills_1_16.xln, gerber_job.gbrjob, pcb-full.GBL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]

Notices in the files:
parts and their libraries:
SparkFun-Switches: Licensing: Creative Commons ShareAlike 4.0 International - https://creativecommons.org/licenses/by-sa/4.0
